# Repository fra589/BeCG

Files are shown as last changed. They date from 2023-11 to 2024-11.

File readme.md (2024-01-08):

<h1 align="center">Balance électronique pour mesure<br />et calculs du Centre de Gravité<br />des modèles réduits d'avion.</h1>

La balance affiche sur son écran les masse mesurées sur les appuis du bord d'attaque et du bord de fuite, la masse totale et la position du centre de gravité en millimètres mesurée à partir de la butée du bord d'attaque de l'aile.
La balance intégre également une interface WiFi qui permet de consulter les mesures et de régler ses paramètres.
1) Soit en se connectant au point d'accès de la balance, par exemple avec un smartphone,
2) soit en connectant la balance à un réseau WiFi existant (après avoir configuré le réseau WiFi à l'aide de la connexion 1.).

Une fois la connexion effectuée, on accède à son interface au travers d'un navigateur web standard.
<p align='center'>
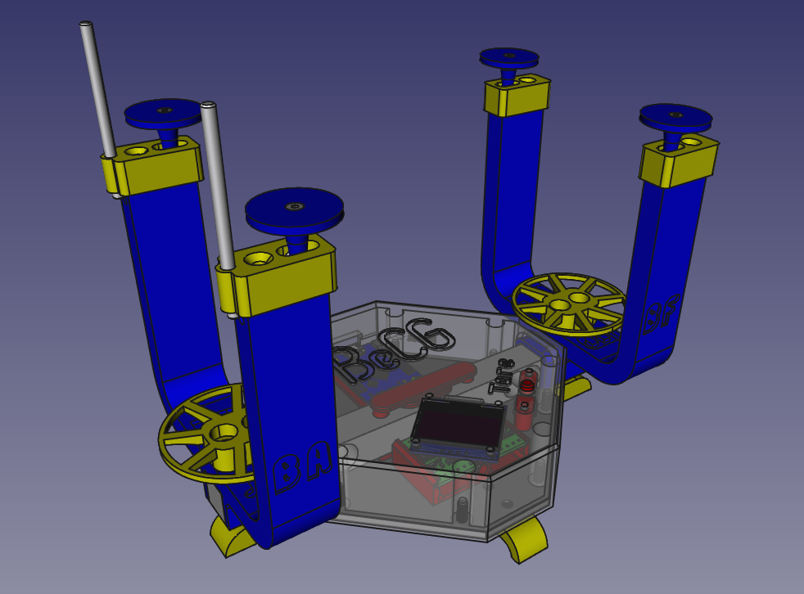
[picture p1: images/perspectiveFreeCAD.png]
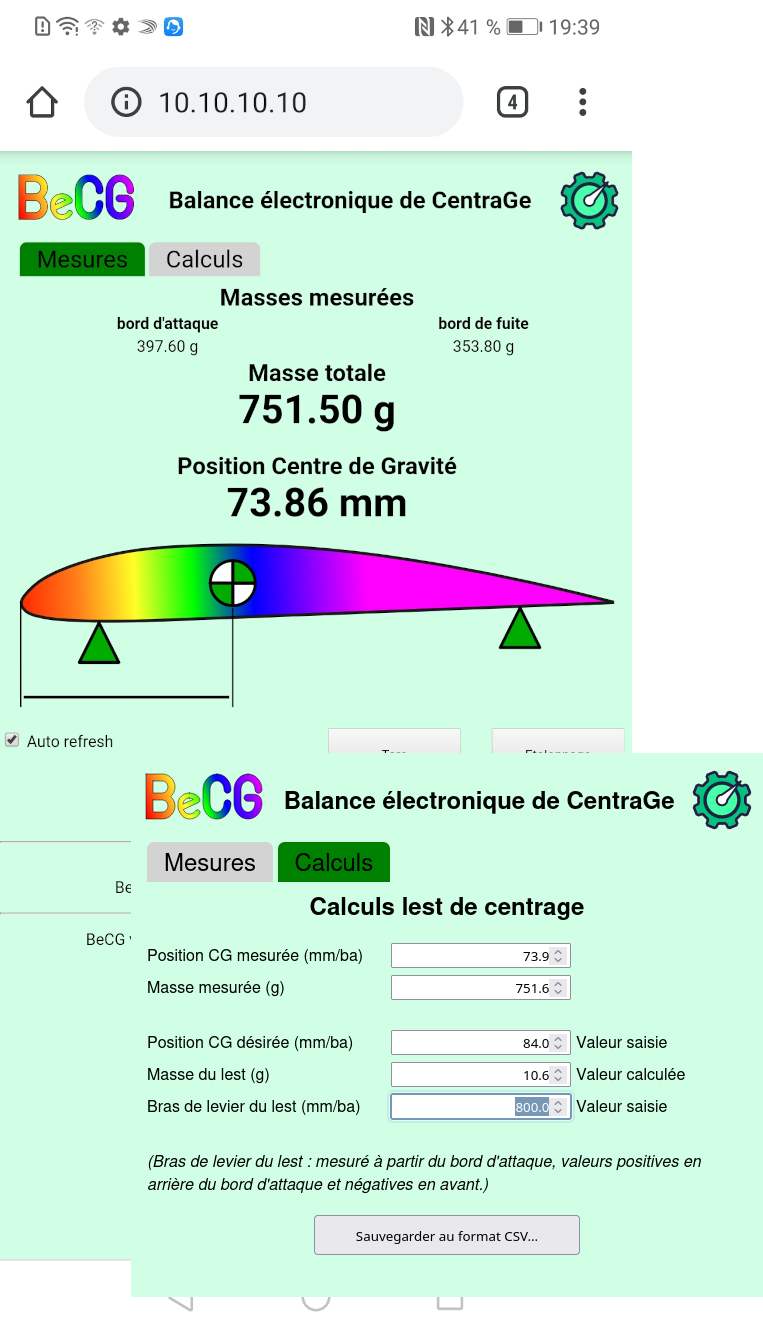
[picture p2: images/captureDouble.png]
&nbsp;&nbsp;&nbsp;&nbsp;&nbsp;
</p>

La balance est basée sur :
- Une carte microcontrôleur WiFi ESP8266 de type Wemos D1 mini, 
- deux capteurs de masse formés par une cellule de charge et un module amplificateur HX711,
- un écran I2C SSD1306 de 0.96 pouce (résolution 128x64),
- une structure imprimée en 3D (avec en option un socle métallique pour plus de rigidité).

La précision de mesure estimée de la masse est de l'ordre de ±0.2g, celle du calcul de centrage est estimée à environ ±0.2mm.

---

<h2 align="center">Les documentations d'installation et d'utilisation se trouvent dans le WiKi :<br />https://github.com/fra589/BeCG/wiki</h2>

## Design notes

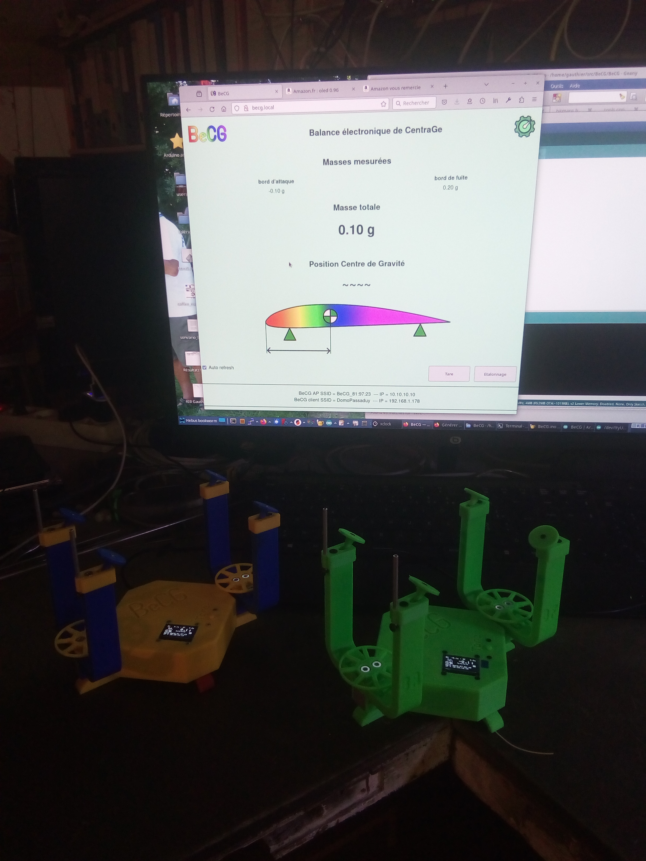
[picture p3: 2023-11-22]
images/proto01+02.jpg

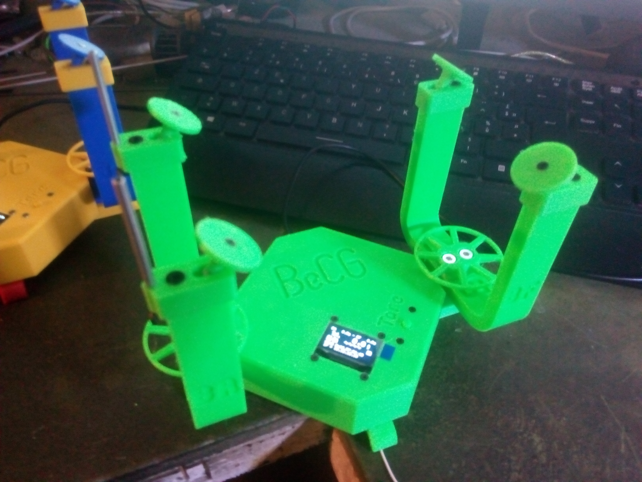
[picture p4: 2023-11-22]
images/proto02-2.jpg

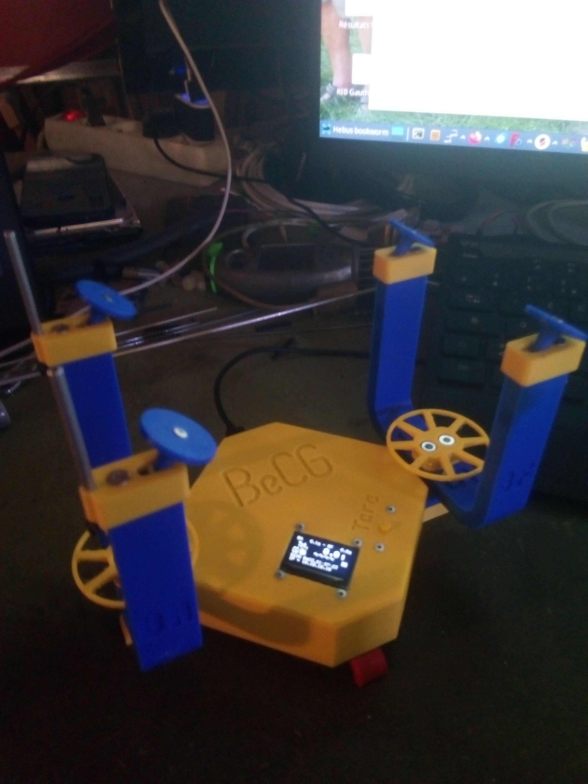
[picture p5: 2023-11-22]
images/proto01-2.jpg

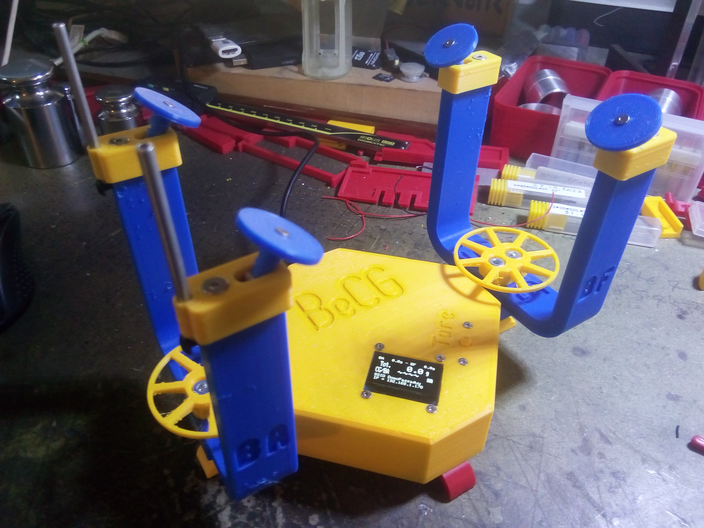
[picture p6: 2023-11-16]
images/proto01-1.jpg

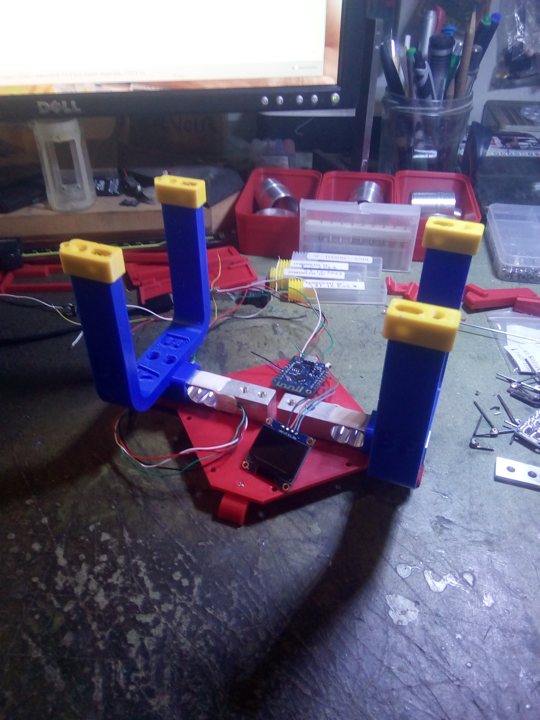
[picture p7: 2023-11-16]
images/proto00.jpg

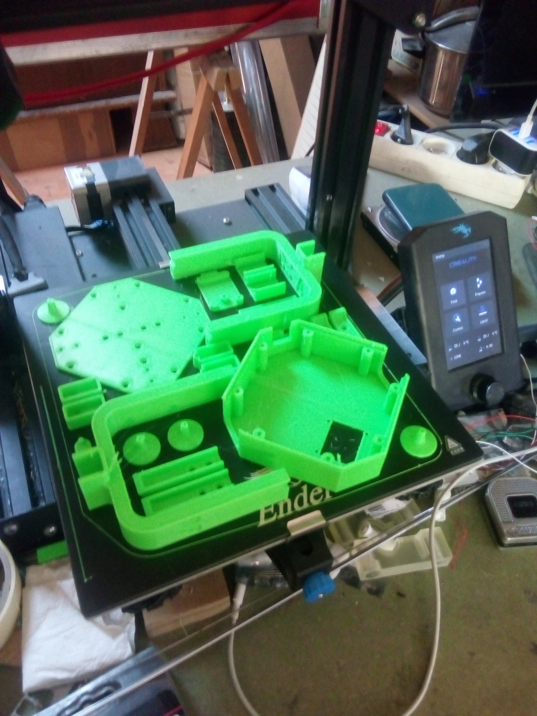
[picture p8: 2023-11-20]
images/proto02-1.jpg

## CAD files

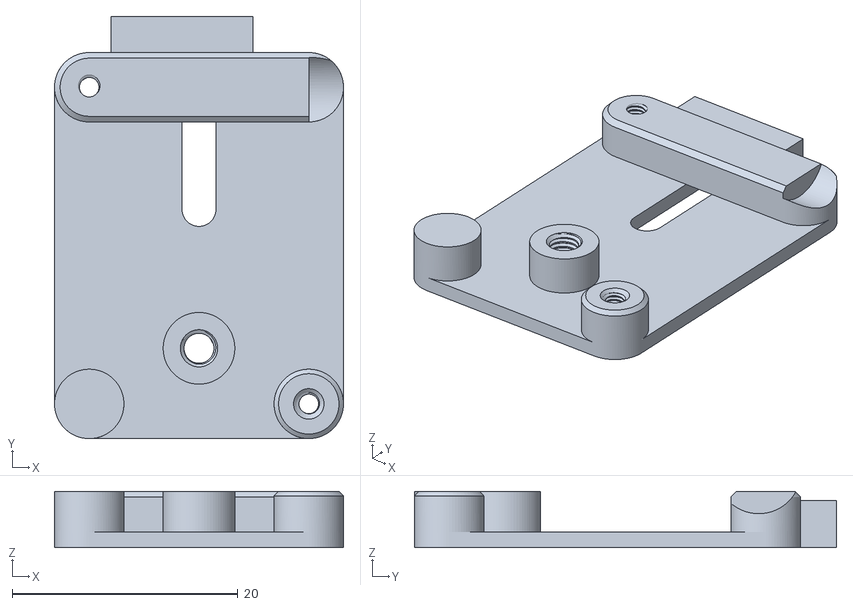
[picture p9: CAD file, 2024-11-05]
freecad/balanceCentrage01-supportWemosD1Mini.stl
25.6 x 37.4 x 5.00

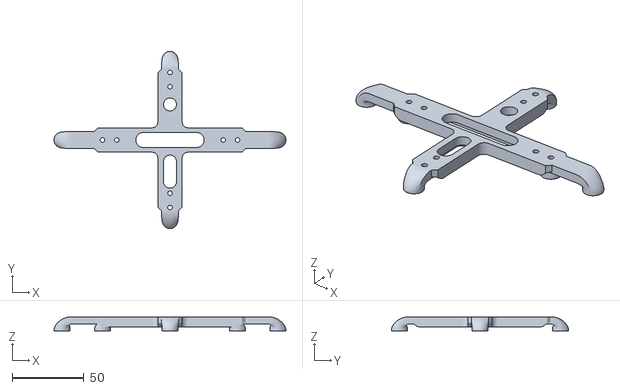
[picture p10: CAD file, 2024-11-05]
freecad/balanceCentrage01-pieds.stl
161.4 x 123.4 x 10.0

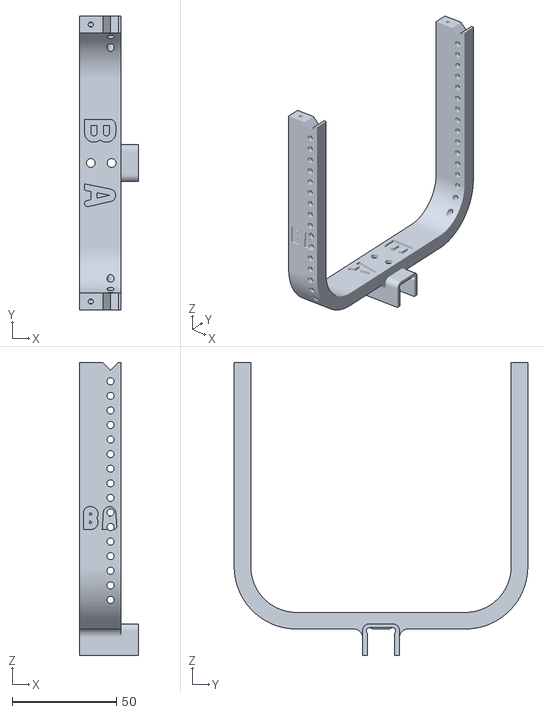
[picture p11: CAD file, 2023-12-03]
freecad/balanceCentrage01-berceauBAlarge.stl
28.5 x 141.0 x 140.7

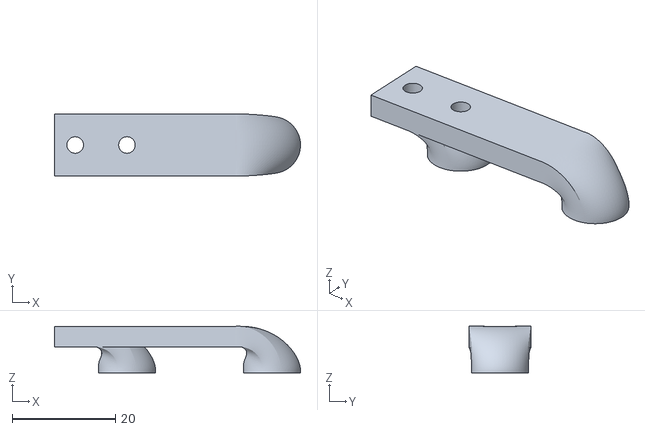
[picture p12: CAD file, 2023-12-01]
freecad/balanceCentrage01-piedLong.stl
47.5 x 12.0 x 9.02

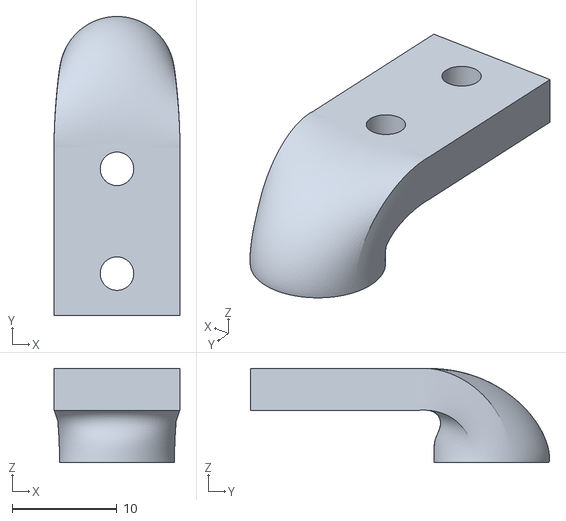
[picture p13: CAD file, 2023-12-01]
freecad/balanceCentrage01-piedCourt.stl
12.0 x 28.5 x 9.02

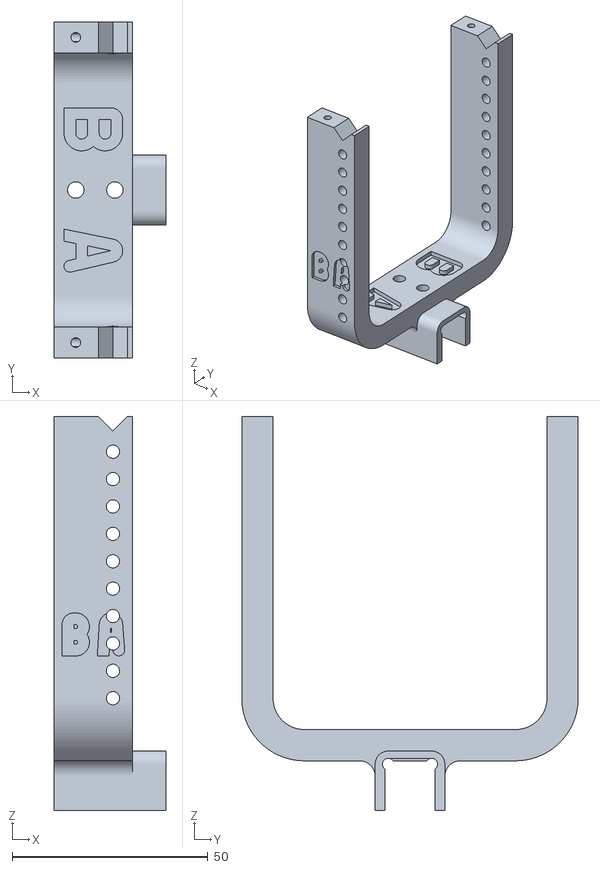
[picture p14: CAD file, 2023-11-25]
freecad/balanceCentrage01-berceauBA.stl
28.5 x 86.0 x 100.7

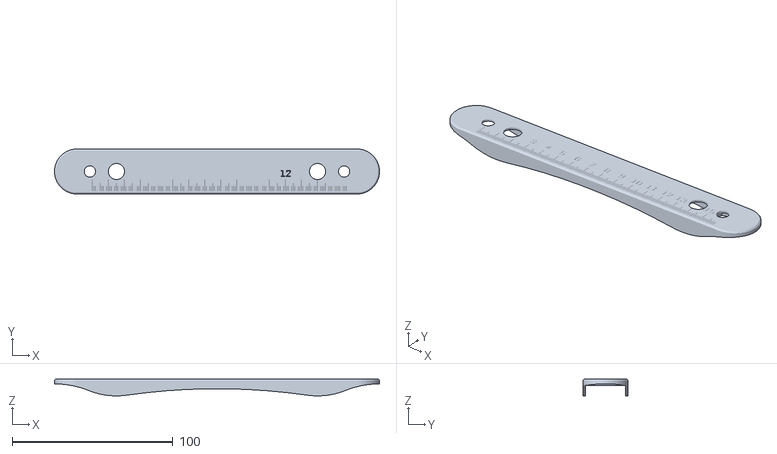
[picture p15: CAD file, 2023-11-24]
freecad/balanceCentrage01-regleAppuis.stl
202.0 x 28.0 x 10.5

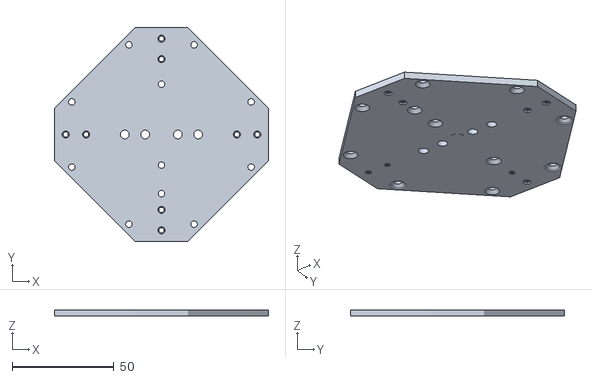
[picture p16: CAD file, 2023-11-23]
freecad/balanceCentrage01-semelle.stl
105.0 x 105.0 x 3.10

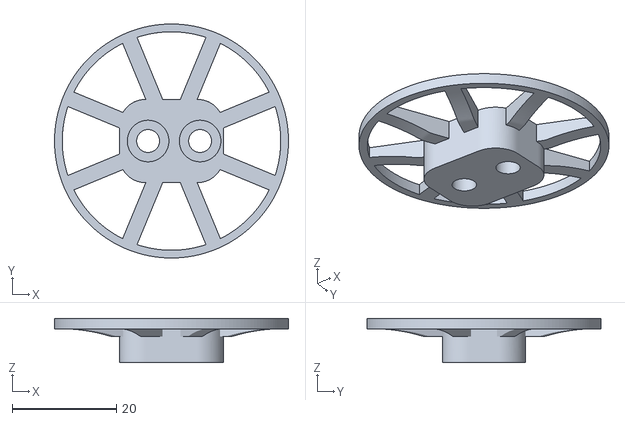
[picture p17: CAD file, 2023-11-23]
freecad/balanceCentrage01-plateauTare.stl
45.0 x 45.0 x 8.50

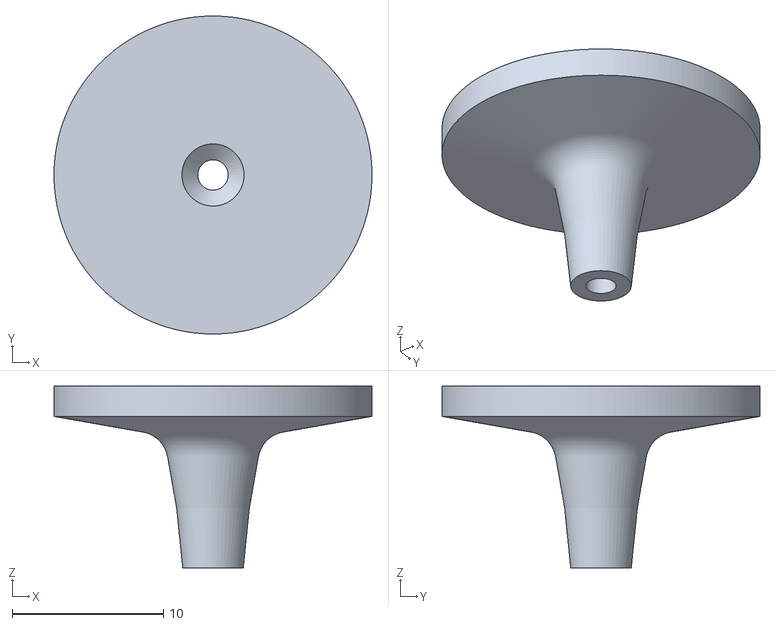
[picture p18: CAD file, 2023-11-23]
freecad/balanceCentrage01-corpsPlot.stl
21.0 x 21.0 x 12.0

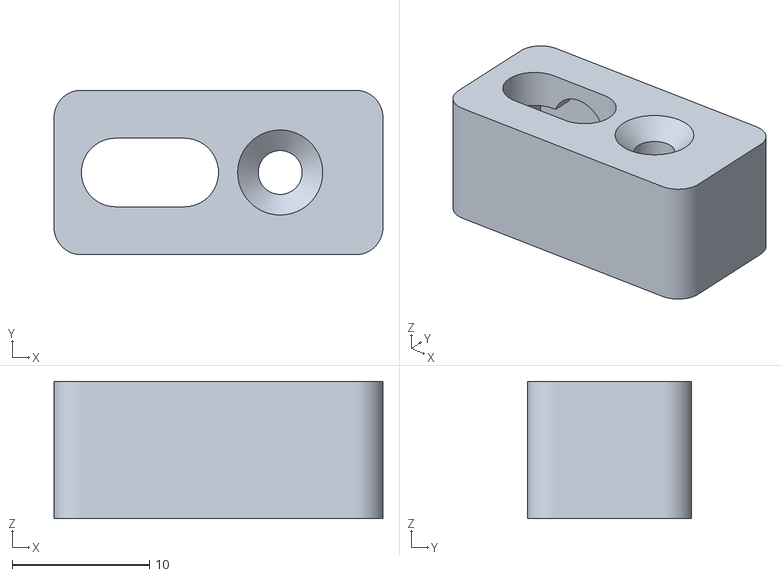
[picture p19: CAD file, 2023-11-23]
freecad/balanceCentrage01-bridePlotBF.stl
24.0 x 12.0 x 10.0

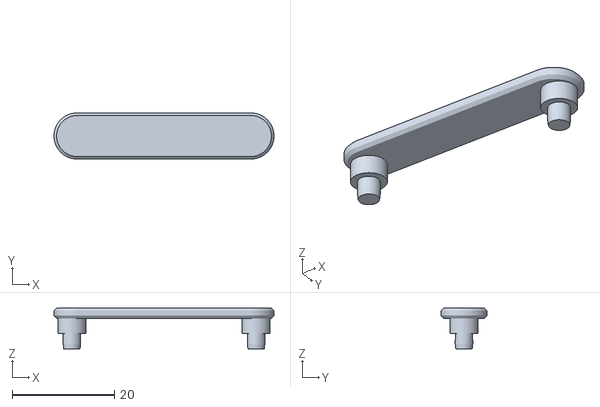
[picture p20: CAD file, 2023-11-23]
freecad/balanceCentrage01-clipFilsLong.stl
43.0 x 9.00 x 8.00

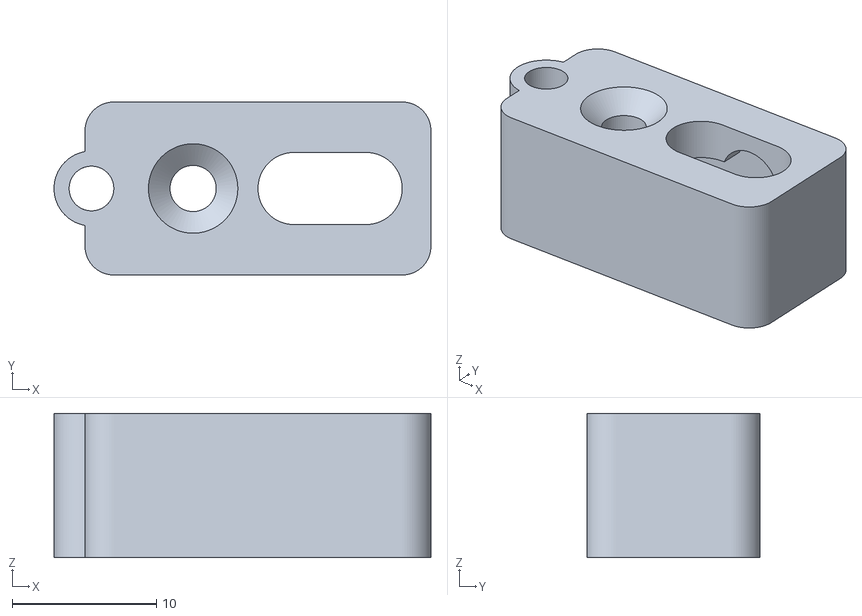
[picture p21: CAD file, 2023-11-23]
freecad/balanceCentrage01-bridePlotBA.stl
26.2 x 12.0 x 10.0

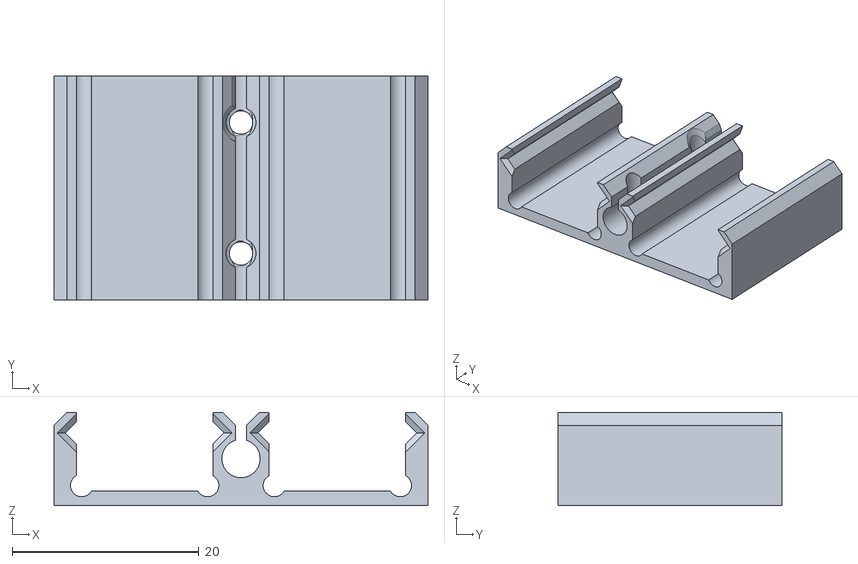
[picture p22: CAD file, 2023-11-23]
freecad/balanceCentrage01-supportHX711.stl
40.0 x 24.0 x 10.0

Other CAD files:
freecad/balanceCentrage01-berceauBFlarge.stl
freecad/balanceCentrage01-berceauBF.stl
freecad/balanceCentrage01-entretoise.stl
freecad/balanceCentrage01-boutonTare.stl
freecad/balanceCentrage01-clipFilsCourt.stl

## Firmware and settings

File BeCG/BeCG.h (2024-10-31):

/****************************************************************************/
/*                                                                          */
/* Copyright (C) 2023-2024 Gauthier Brière (gauthier.briere "at" gmail.com) */
/*                                                                          */
/* This file: BeCG.h is part of BeCG                                        */
/*                                                                          */
/* BeCG is free software: you can redistribute it and/or modify it          */
/* under the terms of the GNU General Public License as published by        */
/* the Free Software Foundation, either version 3 of the License, or        */
/* (at your option) any later version.                                      */
/*                                                                          */
/* BeCG is distributed in the hope that it will be useful, but              */
/* WITHOUT ANY WARRANTY; without even the implied warranty of               */
/* MERCHANTABILITY or FITNESS FOR A PARTICULAR PURPOSE.  See the            */
/* GNU General Public License for more details.                             */
/*                                                                          */
/* You should have received a copy of the GNU General Public License        */
/* along with this program.  If not, see <http://www.gnu.org/licenses/>.    */
/*                                                                          */
/****************************************************************************/

#ifndef BeCG_h
  #define BeCG_h

  #include <stdlib.h>
  #include <Adafruit_SSD1306.h>
  #include <EEPROM.h>
  #include <HX711.h>
  #include <ESP8266WiFi.h>
  #include <ESP8266mDNS.h>
  #include <ESP8266WebServer.h>
  #include <DNSServer.h>
  #include <LittleFS.h>
  #include <ESP8266HTTPUpdateServer.h>

  #include "translate.h"
  #include "TrivialKalmanFilter.h"
  #include "bitmaps.h"
  #include "affichage.h"
  #include "tools.h"
  #include "webserver.h"
  #include "becgwifi.h"

  // Pour debug sur port série
  #define DEBUG
  //#define DEBUG2          // Pour debugs dans la boucle...
  #define DEBUG_WEB       // debug des interractions web
  //#define DEBUG_WEB_VALUE // debug des appels de valeurs web

  #define COPYRIGHT             "G.Bri\x8Are 2023-2024"
  #define ORG_NAME              "fra589"
  #define APP_NAME              "BeCG"
  #define APP_VERSION_MAJOR     "1"
  #define APP_VERSION_MINOR     "0"
  #define APP_VERSION_DATE      "20240718"
  #define APP_VERSION_STRING    "v" APP_VERSION_MAJOR "." APP_VERSION_MINOR "." APP_VERSION_DATE
  #define APP_NAME_VERSION      APP_NAME " - " APP_VERSION_STRING "\0"
  #define EEPROM_VERSION_MAJOR  "0"
  #define EEPROM_VERSION_MINOR  "9"
  #define EEPROM_VERSION_REVIS  "2"
  #define EEPROM_VERSION        APP_NAME " EEPROM v" EEPROM_VERSION_MAJOR "." EEPROM_VERSION_MINOR "." EEPROM_VERSION_REVIS

  #define EEPROM_VERSION_LEN 32
  extern char EEPROM_Version[EEPROM_VERSION_LEN];

  // Adresses EEProm pour sauvegarde des paramètres
  #define EEPROM_LENGTH 512
  #define ADDR_EEPROM_VERSION  0 //   0 + 32 =  32
  #define ADDR_SCALE_BA       32 //  32 +  4 =  36
  #define ADDR_SCALE_BF       36 //  36 +  4 =  40
  #define ADDR_CLI_SSID       40 //  40 + 32 =  72
  #define ADDR_CLI_PWD        72 //  72 + 63 = 135
  #define ADDR_AP_SSID       135 // 135 + 32 = 167
  #define ADDR_AP_PWD        167 // 167 + 63 = 230
  #define ADDR_AP_CHANNEL    230 // 230 +  2 = 232
  #define ADDR_ENTRAXE       232 // 232 +  4 = 236
  #define ADDR_PAF_BA        236 // 236 +  4 = 240
  #define ADDR_MASSE_ETALON  240 // 240 +  2 = 242
  #define ADDR_LANG          242 // 242 +  3

  // Données mécanique de la balance
  #define DEFAULT_ENTAXE          125.0 // (mm) Distance entre las appuis BA et BF
  #define DEFAULT_PAF_BA           15.0 // (mm) Distance entre appuis BA et Cale bord attaque
  #define DEFAULT_MASSE_ETALON    500   // (g) Masse utilisée pour l'étalonnage
  #define DEFAULT_LANG            "fr"
  extern float entraxe;
  extern float pafBA;
  extern int16_t masseEtalon;
  #define LANG_LEN 2
  extern char lang[LANG_LEN + 1];

  // Câblages HX711 
  #define LOADCELL_BA_DOUT_PIN 12 // D6/GPIO12
  #define LOADCELL_BA_SCK_PIN  13 // D7/GPIO13
  extern HX711 hx711_ba;
  #define LOADCELL_BF_DOUT_PIN 16 // D0/GPIO16
  #define LOADCELL_BF_SCK_PIN  14 // D5/GPIO14
  extern HX711 hx711_bf;

  // Echelle par défaut des balances 
  #define DEFAULT_SCALE_BA 385.0
  #define DEFAULT_SCALE_BF 385.0
  extern float scaleBA;
  extern float scaleBF;

  // Bouton tarage
  #define PIN_BOUTON        2 // Pin D4/GPIO2 - Bouton de tarage
  #define BOUTON_ON         0
  #define BOUTON_OFF        1
  #define APPUIS_LONG       2 // 2 secondes

  // Valeurs des paramètres par défauts
  #define DEFAULT_CLI_SSID   ""       // SSID client (la balance se connecte si défini)
  #define DEFAULT_CLI_PWD    ""       // WPA-PSK/WPA2-PSK client
  #define DEFAULT_AP_SSID    "BeCG_"  // SSID de l'AP balance
  #define DEFAULT_AP_PWD     ""       // WPA-PSK/WPA2-PSK AP
  #define DEFAULT_AP_CHANNEL 3

  // Variable globales pour le WiFi
  #define MAX_SSID_LEN 32 // Longueur maxi d'un SSID
  #define MAX_PWD_LEN  63 // Longueur maxi des mots de passe WiFi
  extern char cli_ssid[MAX_SSID_LEN];
  extern char cli_pwd[MAX_PWD_LEN];
  extern char ap_ssid[MAX_SSID_LEN];
  extern char ap_pwd[MAX_PWD_LEN];
  
  // Web server
  extern ESP8266WebServer server;
  extern ESP8266HTTPUpdateServer httpUpdater;
  
  // DNS server
  extern DNSServer dnsServer;
  
  // hostname pour mDNS. devrait fonctionner au moins avec windows :
  // http://BeCG.local
  extern const char *myHostname;

  // Fichiers web
  #define ROOT_FILE "/index.html"

  // Masses et Centre de Gravité
  extern TrivialKalmanFilter<float> filter_ba;
  extern TrivialKalmanFilter<float> filter_bf;
  extern float valeurMoy_ba;
  extern float valeurMoy_bf;
  extern float masseTotale;
  extern float positionCG;

  // Flags pour désactiver le bouton tare et les mesures
  extern bool disableBouton;
  extern bool disableMesure;
  
#endif // BeCG_h

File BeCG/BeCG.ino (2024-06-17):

/****************************************************************************/
/*                                                                          */
/* Copyright (C) 2023-2024 Gauthier Brière (gauthier.briere "at" gmail.com) */
/*                                                                          */
/* This file: BeCG.ino is part of BeCG                                      */
/*                                                                          */
/* BeCG is free software: you can redistribute it and/or modify it          */
/* under the terms of the GNU General Public License as published by        */
/* the Free Software Foundation, either version 3 of the License, or        */
/* (at your option) any later version.                                      */
/*                                                                          */
/* BeCG is distributed in the hope that it will be useful, but              */
/* WITHOUT ANY WARRANTY; without even the implied warranty of               */
/* MERCHANTABILITY or FITNESS FOR A PARTICULAR PURPOSE.  See the            */
/* GNU General Public License for more details.                             */
/*                                                                          */
/* You should have received a copy of the GNU General Public License        */
/* along with this program.  If not, see <http://www.gnu.org/licenses/>.    */
/*                                                                          */
/****************************************************************************/

#include "BeCG.h"


//----------------------------------------------------------------------------
// Variables globales
//----------------------------------------------------------------------------

char EEPROM_Version[EEPROM_VERSION_LEN];
char lang[LANG_LEN + 1];

// Capteurs de masse
HX711 hx711_ba;
HX711 hx711_bf;
// WiFi
char cli_ssid[MAX_SSID_LEN] = DEFAULT_CLI_SSID;
char cli_pwd[MAX_PWD_LEN]   = DEFAULT_CLI_PWD;
char ap_ssid[MAX_SSID_LEN]  = DEFAULT_AP_SSID;
char ap_pwd[MAX_PWD_LEN]    = DEFAULT_AP_PWD;
// mDNS
const char *myHostname = APP_NAME;
// DNS server
const byte DNS_PORT = 53;
DNSServer dnsServer;
// Web server
ESP8266WebServer server(80);
ESP8266HTTPUpdateServer httpUpdater;
// Masses et Centre de Gravité
float valeurMoy_ba = 0.0;
float valeurMoy_bf = 0.0;
float masseTotale = 0.0;
float positionCG = 0.0;

float entraxe       = DEFAULT_ENTAXE;
float pafBA         = DEFAULT_PAF_BA;
int16_t masseEtalon = DEFAULT_MASSE_ETALON;
float scaleBA       = DEFAULT_SCALE_BA;
float scaleBF       = DEFAULT_SCALE_BF;

// Flag pour attente des services web
bool reset_scale_en_cours = false;
bool tare_en_cours        = false;
bool etalonnage_en_cours  = false;
  // Flags pour désactiver le bouton tare et les mesures
bool disableBouton = false;
bool disableMesure = false;

//#define DT_COVARIANCE_RK 4.7e-3 // Estimation of the noise covariances (process)
//#define DT_COVARIANCE_QK 1e-5   // Estimation of the noise covariances (observation)
//#define DT_COVARIANCE_RK 0.00468921411002 // Estimation of the noise covariances (process)
//#define DT_COVARIANCE_QK 0.00468921411002   // Estimation of the noise covariances (observation)
#define DT_COVARIANCE_RK 0.002   // Estimation of the noise covariances (process)
#define DT_COVARIANCE_QK 0.00025 // Estimation of the noise covariances (observation)
TrivialKalmanFilter<float> filter_ba(DT_COVARIANCE_RK, DT_COVARIANCE_QK);
TrivialKalmanFilter<float> filter_bf(DT_COVARIANCE_RK, DT_COVARIANCE_QK);

void setup() {
  // Try pushing frequency to 160MHz.
  bool update_cpu_freq = system_update_cpu_freq(160);

  #if defined(DEBUG) || defined(DEBUG2) || defined(DEBUG_WEB) || defined(DEBUG_WEB_VALUE)
    // Init port série pour debug
    Serial.begin(115200);
    Serial.setDebugOutput(true);
    Serial.flush();
    Serial.println();
    Serial.flush();
  #endif

  #ifdef DEBUG
    //int cpuFreq = ESP.getCpuFreqMHz();
    int cpuFreq = system_get_cpu_freq();
    Serial.printf("\nStarting %s on ESP8266@%dMHz (system_update_cpu_freq() = %s)...\n\n", APP_NAME_VERSION, cpuFreq, update_cpu_freq?"true":"false");
    Serial.flush();
  #endif

  // Hardware init
  pinMode(PIN_BOUTON, INPUT_PULLUP);

  // Init affichage
  affichage_init();
  afficheSplash();

  // Récupération des paramètres EEPROM
  getEepromStartupData();
  
  // Initialisation du WiFi
  wifiApInit();
  wifiClientInit();

  // Démarrage du serveur web
  webServerInit();

  // Initialisation des balances
  balancesInit();

  delay(1000);
  
  // Effacement splash et affichage du pied de page
  clearDisplay();
  affichePiedPage();

}


void loop() {

  unsigned long debut = 0;
  unsigned long now = 0;
  float masse_ba = 0.0;
  float masse_bf = 0.0;
  int digitAffiche = -1;
  int digit = 0;

  // Pour laisser du temps au WiFi...
  delay(10);
  // https://forum.arduino.cc/t/yield-utilite-fonctionnement/883558
  yield();

  //DNS
  dnsServer.processNextRequest();
  if (WiFi.status() == WL_CONNECTED) {
    MDNS.update();
  }

  // Pour laisser du temps au WiFi...
  delay(10);
  // https://forum.arduino.cc/t/yield-utilite-fonctionnement/883558
  yield();

  //HTTP
  server.handleClient();

  // Pour laisser du temps au WiFi...
  delay(10);
  // https://forum.arduino.cc/t/yield-utilite-fonctionnement/883558
  yield();

  // Etat du bouton de tarrage
  if (!disableBouton) {
    int etat_bouton = digitalRead(PIN_BOUTON);
    if (etat_bouton == BOUTON_ON) {
      debut = millis();
      do {
        // Affiche les secondes d'appuis sur l'écran
        if (digitAffiche < 0) {
          digitAffiche = afficheDigit(0);
        } else {
          digit = (int)((millis() - debut)/1000);
          if (digit > 9) {
            // Un appuis de plus de 10 secondes fait rebooter la balance
            ESP.restart();
          }
          // met à jour l'affichage du digit à chaque seconde
          if (digit != digitAffiche) {
            digitAffiche = afficheDigit(digit);
          }
        }
        etat_bouton = digitalRead(PIN_BOUTON);
        delay(1);
        // https://forum.arduino.cc/t/yield-utilite-fonctionnement/883558
        yield();
      } while (etat_bouton != BOUTON_OFF);
      now = millis();
      if ((now - debut) > (APPUIS_LONG * 1000)) {
        #ifdef DEBUG
          Serial.printf("Etalonnages balances...\n");
        #endif
        etalonnage(); // Etalonnages avec une masse connue...
      } else {
        afficheMessage("\n   Remise à zéro\n   balances...");
        #ifdef DEBUG
          Serial.printf("Remise à zéro balances.\n");
        #endif
        tare();
      }
    }
  } // if (!disableBouton)

  // Pour laisser du temps au WiFi...
  delay(10);
  // https://forum.arduino.cc/t/yield-utilite-fonctionnement/883558
  yield();

  if (!disableMesure) {
    // Mesure des masses
    if (hx711_ba.wait_ready_timeout(1000, 5) && hx711_bf.wait_ready_timeout(1000, 5)) {
      debut = millis();
      masse_ba = hx711_ba.get_units();
      masse_bf = hx711_bf.get_units();
      now = millis();

      yield();

      // On applique le filtre de Kalman
      valeurMoy_ba = filter_ba.update(masse_ba);
      valeurMoy_bf = filter_bf.update(masse_bf);

      yield();

      #ifdef DEBUG2
        /*
        Serial.printf("%0.5f %0.5f\n", masse_ba, valeurMoy_ba);
        Serial.printf("%0.5f %0.5f\n", masse_bf, valeurMoy_bf);
        */
        Serial.printf("HX711 masses BA = %+0.1f,\tBF = %+0.1f,\tfiltrées BA = %+0.1f,\tBF = %+0.1f\n", \
                      masse_ba, \
                      masse_bf, \
                      valeurMoy_ba, \
                      valeurMoy_bf \
        );
      #endif // DEBUG2
    } else {
      afficheMessage("\n   Erreur capteur\n   de masse !");
      #ifdef DEBUG2
        Serial.printf("HX711 missing.\t");
      #endif
    }

    // On force l'arrondi à une décimale de la somme, ce qui évite l'affichage de -0.0
    masseTotale = roundf((valeurMoy_ba + valeurMoy_bf) * 10) / 10;
    // Puis, on arrondi les masse BA et BF après en avoir fait la somme
    valeurMoy_ba = roundf(valeurMoy_ba * 10) /10;
    valeurMoy_bf = roundf(valeurMoy_bf * 10) /10;

    // Affichage :
    afficheMasse_BA_BF(valeurMoy_ba, valeurMoy_bf);
    afficheMasseTotale(masseTotale);
    if ((abs(valeurMoy_ba) < 3) && (abs(valeurMoy_bf) < 3)) {
      // Il faut une masse mini de 3 grammes sur l'un des capteurs
      // pour déclencher le calcul et afficher le centrage. 
      positionCG = 0.0;
    } else {
      positionCG = pafBA + ((entraxe * valeurMoy_bf)/(valeurMoy_ba + valeurMoy_bf));
    }
    afficheCG(positionCG);
    
  } // if (!disableMesure)

  // Pour laisser du temps au WiFi...
  delay(10);
  // https://forum.arduino.cc/t/yield-utilite-fonctionnement/883558
  yield();

}

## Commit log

2023-11-20 suite du dev de l'interface web
2023-11-22 Version 0.8 - première version utilisable
    [balanceCentrage01-berceauRetreci.FCStd]
2023-11-23 Correction affichage + ajout reboot sur appuis long sur Tare
    [BeCG.h, BeCG.ino, tools.cpp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]
2023-11-23 Ajout des fichiers STL
    [balanceCentrage01-berceauBA.stl, balanceCentrage01-berceauBF.stl, balanceCentrage01-berceauRetreci-berceauBA.stl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]
2023-11-24 Ajout graduations sur les règles
2023-11-24 Correction graduation sur modèle FreeCAD
    [balanceCentrage01-regleAppuis.stl]
2023-11-24 Retouche convercle.stl
2023-11-25 Ajout percages sur berceaux
    [balanceCentrage01-berceauBA.stl, balanceCentrage01-berceauBF.stl]
2023-12-01 Pieds modifiés
    [balanceCentrage01-piedCourt.stl, balanceCentrage01-piedspiedLong.stl]
2023-12-01 Ajout sauvegarde des données
    [balanceCentrage01-piedLong.stl]
2023-12-01 suppression agencement plateau imprimante obsolète
2023-12-03 Ajout berceaux larges
    [balanceCentrage01-berceauBAlarge.stl, balanceCentrage01-berceauBFlarge.stl]
2023-12-05 Correction startup CPU frequence
    [BeCG.ino]
2023-12-17 renomme fichiers
    [balanceCentrage01-berceauBAretreci.stl, balanceCentrage01-berceauBFretreci.stl]
2023-12-24 Suppression répertoire doc (la doc est dans le wiki)
2024-01-08 supression pièces inutiles
    [balanceCentrage01-berceauBAretreci.stl, balanceCentrage01-berceauBFretreci.stl, balanceCentrage01-berceauRetreci.FCStd]
2024-01-22 Correction bug plantage a l'initialisation des balances
    [tools.cpp]
2024-01-22 mise a jour version suite à correction bug
    [BeCG.h]
2024-02-28 Correction bug WiFi - Correction erreur sur adressage EPROM - Ajoute delay() + yield() dans la loop pour laisser + de temps de traitement au WiFi - Modification Copyright 2023-2023 -> 2023-2024
    [BeCG.h, BeCG.ino, becgwifi.cpp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]
2024-06-16 wifi client init correction
    [becgwifi.cpp]
2024-07-15 correction bug init balances
    [tools.cpp]
2024-11-05 Update FreeCAD model
    [balanceCentrage01-pieds.stl, balanceCentrage01-supportWemosD1Mini.stl]
